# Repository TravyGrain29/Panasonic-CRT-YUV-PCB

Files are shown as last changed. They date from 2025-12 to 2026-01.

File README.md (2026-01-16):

# Panasonic-CRT-YUV-PCB
## DISCLAIMER
I'm not a professional, this was a side project I completed for fun. I cannot guarantee compatibility with your model CRT. I am not responsible for any damage or harm you may inflict upon yourself or your devices. Working on CRTs is very dangerous and should only be done by individuals with the required knowledge and experience. Do not attempt this project if you are a novice with electronics or CRTs.

## Overview

### CRT Specs
Model: Panasonic Tau TC-21PM50A

Chassis: GP3

UOC IC/Jungle: TDA9590N48AX

### What is this?
This is a PCB I designed, based off exisiting Panasonic schematics, that allows Panasonic Tau CRTs using the GP3 chassis to accept component (YPbPr) video input. This is intended for use with GP3 CRTs that lack native component or RGB inputs. The board converts incoming YPbPr signals from an external device into sigals that the video processor can understand and display properly. Without this PCB, the video will not display correctly and will appear distorted.

### How does it work?
Panasonic CRTs that utilise the GP3 chassis but lack component input, still have the basic foundations present that allow us to provide our own component input. This is due to Panasonic reusing the same chassis and processors between higher end and lower end models. All that was required for this mod was to unlock component input as an AV option via the service menu and then installing the missing hardware and connections. This board replaces the missing YUV circuit board that came with component enabled models, allowing us to build the YUV input path ourselves.

### How can I build this?
A written guide will be provided in PDF format with instructions on how to perform the modification.

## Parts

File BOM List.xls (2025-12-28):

YUV CIRCUIT V2
Mouser No | Mfr. No | Manufacturer | Description | Part ID | Order Qty. | Price (AUD) | Ext.: (AUD)
647-UBW1H331MHD | UBW1H331MHD | Nichicon | Aluminium Electrolytic Capacitors - Radial Leaded 50 Volts 330uF AEC-Q200 | C81 | 2 | $2.77 | $5.54
232-16MU226MD35750 | 16MU226MD35750 | Rubycon | Film Capacitors THIN FILM ACRYLIC DIELECTRIC | CB1, CR1 | 2 | $19.71 | $39.42
667-ERA-6AED102V | ERA-6AED102V | Panasonic | Thin Film Resistors - SMD 0805 1000ohms 25ppm 0.5% AEC-Q200 | RB7, RR7, RB8, RR8 | 10 | $0.19 | $1.90
667-ERA-6AED222V | ERA-6AED222V | Panasonic | Thin Film Resistors - SMD 0805 2200ohms 25ppm 0.5% AEC-Q200 | RB6, RR6, RB9, RR9 | 10 | $0.123 | $1.23
667-ERA-6AED122V | ERA-6AED122V | Panasonic | Thin Film Resistors - SMD 0805 1200ohms 25ppm 0.5% AEC-Q200 | RR5 | 10 | $0.19 | $1.90
667-ERA-6AED562V | ERA-6AED562V | Panasonic | Thin Film Resistors - SMD 0805 5600ohms 25ppm 0.5% AEC-Q200 | RR4 | 10 | $0.19 | $1.90
667-ERA-6AED821V | ERA-6AED821V | Panasonic | Thin Film Resistors - SMD 0805 820ohms 25ppm 0.5% AEC-Q200 | RB5 | 10 | $0.19 | $1.90
667-ERA-6AED472V | ERA-6AED472V | Panasonic | Thin Film Resistors - SMD 0805 4700ohms 25ppm 0.5% AEC-Q200 | RB4 | 10 | $0.123 | $1.23
667-ERA-6AED183V | ERA-6AED183V | Panasonic | Thin Film Resistors - SMD 0805 18Kohms 25ppm 0.5% AEC-Q200 | RB3, RR3 | 10 | $0.19 | $1.90
667-ERA-6AED823V | ERA-6AED823V | Panasonic | Thin Film Resistors - SMD 0805 82Kohms 25ppm 0.5% AEC-Q200 | RB2, RR2 | 10 | $0.19 | $1.90
667-ERA-6AED750V | ERA-6AED750V | Panasonic | Thin Film Resistors - SMD 0805 75ohms 25ppm 0.5% AEC-Q200 | RY1, RB1, RR1 | 10 | $0.19 | $1.90
710-885012207078 | 885012207078 | Wurth Elektronik | Multilayer Ceramic Capacitors MLCC - SMD/SMT WCAP-CSGP 1uF 0805 10% 25V MLCC | CB4, CR4 | 10 | $0.173 | $1.73
994-LPS3010-822MRC | LPS3010-822MRC | Coilcraft | Power Inductors - SMD 8.2uH Shld 20% 520mOhms AECQ2 | L81 | 2 | $2.14 | $4.28
77-VJ0805A221KXCAC | VJ0805A221KXCAC | Vishay | Multilayer Ceramic Capacitors MLCC - SMD/SMT 220pF 200volts C0G 10% | CB2, CR2, CB3, CR3 | 10 | $0.448 | $4.48
81-LQM2HPN2R2MG0L | LQM2HPN2R2MG0L | Murata | Power Inductors - SMD 2.2 UH 20% | LB1, LR1 | 10 | $0.274 | $2.74
833-2SC1623-L6-TP | 2SC1623-L6-TP | Micro Commercial Components (MCC) | Bipolar Transistors - BJT Small Signal Bipolar Transistors | QB1, QR1, QB2, QR2, QB3, QR3 | 20 | $0.144 | $2.88
80-C1206C473F5GECTU | C1206C473F5GECTU | KEMET | Multilayer Ceramic Capacitors MLCC - SMD/SMT 50V 0.047uF C0G 1206 1% | CY1 | 2 | $4.90 | $9.80

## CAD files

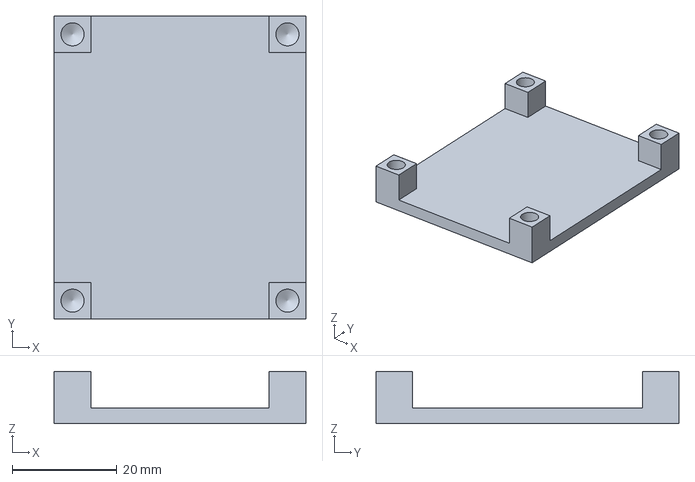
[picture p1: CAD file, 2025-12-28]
YUV PCB Bracket 3mf/YUV V2.FCStd
48.0 x 57.8 x 10.0 mm

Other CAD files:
YUV PCB Bracket 3mf/YUV V2.3mf

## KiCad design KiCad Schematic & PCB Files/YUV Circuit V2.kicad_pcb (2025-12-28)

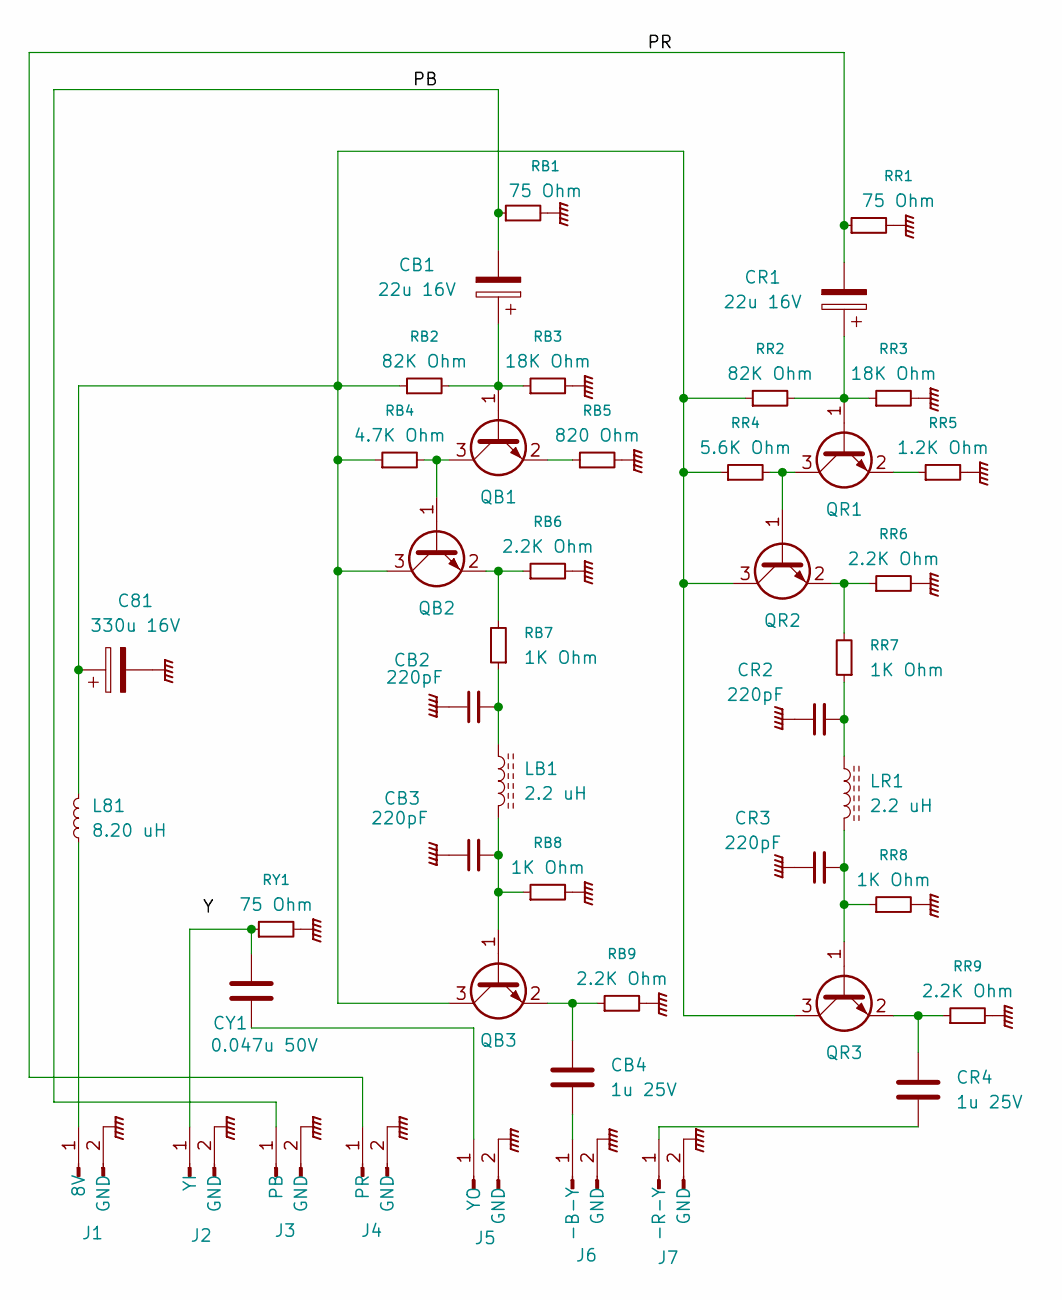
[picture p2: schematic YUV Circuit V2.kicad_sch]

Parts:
C81: 330u 16V; CP_Radial_D12.5mm_P5.00mm
CB1: 22u 16V; C_2220_5750Metric_Pad1.97x5.40mm_HandSolder
CB2, CB3: 220pF; C_0805_2012Metric_Pad1.18x1.45mm_HandSolder
CB4: 1u 25V; C_0805_2012Metric_Pad1.18x1.45mm_HandSolder
CR1: 22u 16V; C_2220_5750Metric_Pad1.97x5.40mm_HandSolder
CR2, CR3: 220pF; C_0805_2012Metric_Pad1.18x1.45mm_HandSolder
CR4: 1u 25V; C_0805_2012Metric_Pad1.18x1.45mm_HandSolder
CY1: 0.047u 50V; C_1206_3216Metric_Pad1.33x1.80mm_HandSolder
J1, J2, J3, J4, J5, J6, J7: Conn_01x02_Pin; JST_EH_B2B-EH-A_1x02_P2.50mm_Vertical
L81: 8.20 uH; L_Coilcraft_LPS3010
LB1: 2.2 uH; L_1008_2520Metric_Pad1.43x2.20mm_HandSolder
LR1: 2.2 uH; L_1008_2520Metric_Pad1.43x2.20mm_HandSolder
QB1: SOT-23-3
QB2, QB3: Q_NPN; SOT-23-3
QR1: SOT-23-3
QR2, QR3: Q_NPN; SOT-23-3
RB1: 75 Ohm; R_0805_2012Metric_Pad1.20x1.40mm_HandSolder
RB2: 82K Ohm; R_0805_2012Metric_Pad1.20x1.40mm_HandSolder
RB3: 18K Ohm; R_0805_2012Metric_Pad1.20x1.40mm_HandSolder
RB4: 4.7K Ohm; R_0805_2012Metric_Pad1.20x1.40mm_HandSolder
RB5: 820 Ohm; R_0805_2012Metric_Pad1.20x1.40mm_HandSolder
RB6, RB9: 2.2K Ohm; R_0805_2012Metric_Pad1.20x1.40mm_HandSolder
RB7, RB8: 1K Ohm; R_0805_2012Metric_Pad1.20x1.40mm_HandSolder
RR1: 75 Ohm; R_0805_2012Metric_Pad1.20x1.40mm_HandSolder
RR2: 82K Ohm; C_0805_2012Metric_Pad1.18x1.45mm_HandSolder
RR3: 18K Ohm; R_0805_2012Metric_Pad1.20x1.40mm_HandSolder
RR4: 5.6K Ohm; R_0805_2012Metric_Pad1.20x1.40mm_HandSolder
RR5: 1.2K Ohm; R_0805_2012Metric_Pad1.20x1.40mm_HandSolder
RR6, RR9: 2.2K Ohm; R_0805_2012Metric_Pad1.20x1.40mm_HandSolder
RR7, RR8: 1K Ohm; R_0805_2012Metric_Pad1.20x1.40mm_HandSolder
RY1: 75 Ohm; R_0805_2012Metric_Pad1.20x1.40mm_HandSolder

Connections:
/PB: CB1.2, J3.1 (PB), RB1.1
/PR: CR1.2, J4.1 (PR), RR1.1
GNDPWR: C81.2, CB2.1, CB3.1, CR2.1, CR3.1, J1.2 (GND), J2.2 (GND), J3.2 (GND), J4.2 (GND), J5.2 (GND), J6.2 (GND), J7.2 (GND), RB1.2, RB3.2, RB5.2, RB6.2, RB8.2, RB9.2, RR1.2, RR3.2, RR5.2, RR6.2, RR8.2, RR9.2, RY1.2
unnamed: CB2.2, LB1.1, RB7.1
unnamed: CR2.2, LR1.1, RR7.1
unnamed: J1.1 (8V), L81.1
unnamed: CY1.1, J2.1 (YI), RY1.1
unnamed: CY1.2, J5.1 (YO)
unnamed: CB4.2, J6.1 (-B-Y)
unnamed: CR4.2, J7.1 (-R-Y)
unnamed: CB1.1, QB1.1 (B), RB2.2, RB3.1
unnamed: QB1.3 (C), QB2.1 (B), RB4.2
unnamed: QB1.2 (E), RB5.1
unnamed: C81.1, L81.2, QB2.3 (C), QB3.3 (C), QR2.3 (C), QR3.3 (C), RB2.1, RB4.1, RR2.1, RR4.1
unnamed: QB2.2 (E), RB6.1, RB7.2
unnamed: CB3.2, LB1.2, QB3.1 (B), RB8.1
unnamed: CB4.1, QB3.2 (E), RB9.1
unnamed: CR1.1, QR1.1 (B), RR2.2, RR3.1
unnamed: QR1.3 (C), QR2.1 (B), RR4.2
unnamed: QR1.2 (E), RR5.1
unnamed: QR2.2 (E), RR6.1, RR7.2
unnamed: CR3.2, LR1.2, QR3.1 (B), RR8.1
unnamed: CR4.1, QR3.2 (E), RR9.1

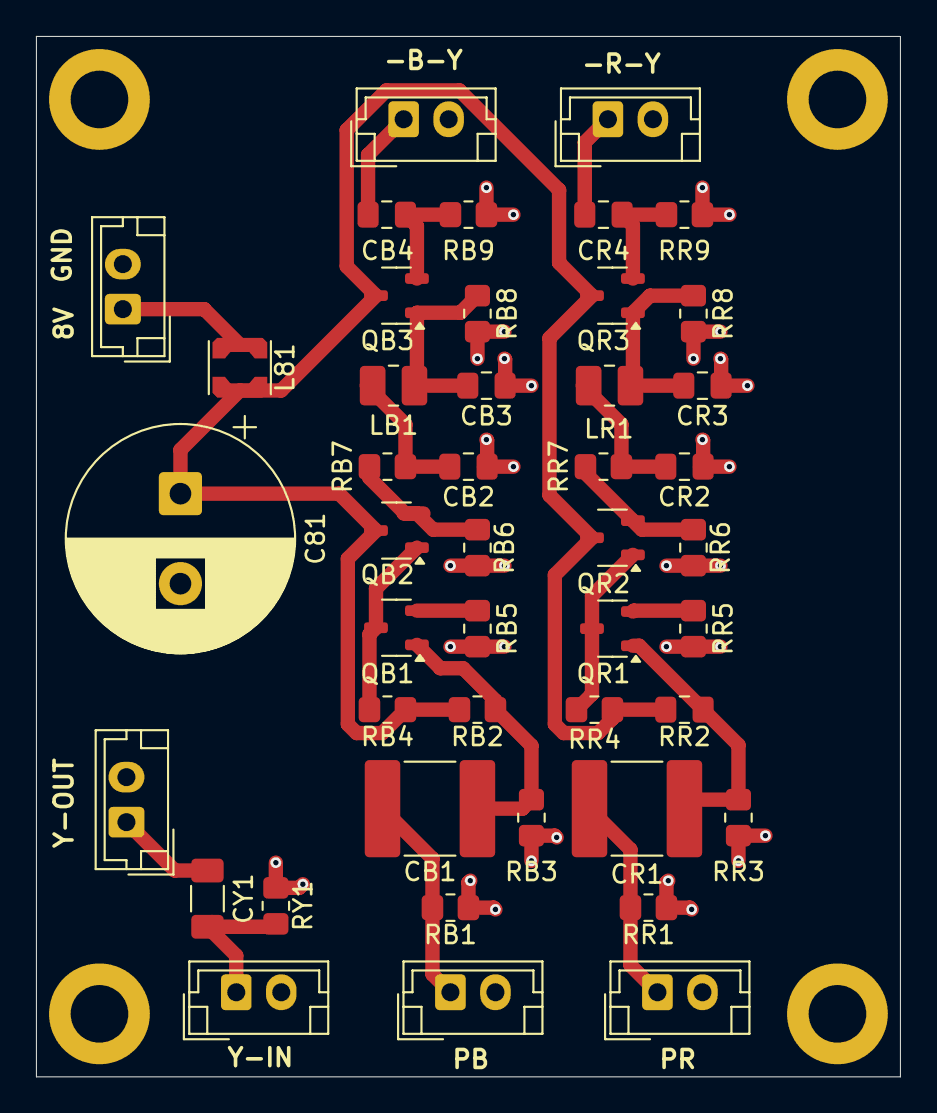
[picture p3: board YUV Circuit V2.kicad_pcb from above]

Board: 2 copper layers, 48.0 x 57.8 mm, 45 parts (0 on the bottom side), 23 nets.
